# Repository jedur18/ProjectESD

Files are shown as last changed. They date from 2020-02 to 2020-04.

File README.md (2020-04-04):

# ESD project
**Project:** Motion Sensor Alarm (Group 2)
General Description: This project is divided in two groups. Group 1 will work with the motion sensor and will transmit a signal to the cloud when alarm is activated. Group 2 will work with the buzzer, display and keyboard in order to introduce the code to switch the alarm off.

**Group 2 description:** Our system will recive the signal of the activated alarm from the cloud by the LORA module. The idea then is to activate the buzzer to emit the sound. While the alarm is ringing the user will be able to introduce a secret code using the keyboard to switch the alarm off. In the display it will be showed the status of the system (Alarm ON/OFF), the code introduced and if it is correct or not.

**Distribution of the work:**
- EDU:
  - Basic part:
    - Numeric Keyboard: With this part digital I/O will be faced. I will also need to remove the bouncing of the buttons, deal with PCINTs (Pin change interruptions).
  - Individual Goals to reach 4/5 mark:
    - Display: SPI communication. Showing the system state, the code introduced by the user and if the code is correct or not.
    - Software protection--> Encryption. Asymmetric encryption if its possible (need to investigate on it)

- ALI:
  - basic part:
    - Buzzer: sendig out sound by the PWM signals as the LEDs.
    - LEDs control. Green:normal mode. Red:alarm mode. (LED blinking-->PWM)
  - More advansed part for us electronic backgrounded students is software development:
    - We are going to make the keypad unit and the sensor unit works as front end which will communicate to the back end server.
    - We are even going to make it possible for the system to be able to support more than one sensor and make it possibble for the master to identify which unit is detecting motions.

## EQUIPMENT:
- Murata CMWX1ZZABZLoRa Module:
	Datasheet:https://wireless.murata.com/datasheet?/RFM/data/type_abz.pdf
  - STM32L0x2:
		Documentation (Full information about micro): https://www.ece.uvic.ca/~ece355/lab/supplement/stm32f0RefManual.pdf
		With rust: https://docs.rs/stm32f0x2/0.1.0/stm32f0x2/

- Oled Display: SSD1306. 
	Datasheet: https://buildmedia.readthedocs.org/media/pdf/ssd1306/latest/ssd1306.pdf
	Website to order: https://cdon.se/hem-tradgard/oled-display-0-96-tum-med-128x64-vita-pixlar-i2c-ssd1306-p50542494
	Prize: 59kr
- Driver for Oled Display SSD1306
	Datasheet: https://cdn-shop.adafruit.com/datasheets/SSD1306.pdf
- LEDs: (Maybe available at lab)
	Red LED: https://se.rs-online.com/web/p/leds/2285988/
	Green LED: https://se.rs-online.com/web/p/leds/2286004/
- Numeric Keyboard:
	Website to order: https://www.elfa.se/en/3x4-matrix-keypad-adafruit-3845/p/30139179?queryFromSuggest=true
	Prize: 61.90kr
	Documentation: https://www.adafruit.com/product/1824
					https://www.futurlec.com/Keypad3x4.shtml
					Arduino libraries and documentation: https://playground.arduino.cc/Code/Keypad/
- Capacitors:
	6x100nF for decoupling: 
			for power supply:

- Resistors: 
	2x10k for pull Up and pull Down resistors for NRST and BOOT0: https://www.elfa.se/en/thick-film-smd-resistor-0805-10kohm-125mw-rnd-components-rnd-1550805s8f1002t5e/p/30056718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
	Prize: 0.4972 (ordering 4)
	for power supply: 
	
- Serial Wire Debug (SWD) to program and debug the MCU: 
	Website to oder: https://www.elfa.se/en/ampmodu-mod-ii-straight-male-pcb-header-through-hole-54mm-te-connectivity-826629/p/14371639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
	Prize: 5.78SEK
	Datasheet:https://www.elfa.se/Web/Downloads/_t/ds/8266xx_x_eng_tds.pdf?pid=14371639

- Power Supply:

- Buzzer: 
  - piezo buzzer (KMTG1603-1) : https://se.rs-online.com/web/p/piezo-buzzer-components/7675349/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
    - Datasheet: https://docs.rs-online.com/aa51/0900766b81113b92.pdf
  - Transistor: (MMBT2222A)
    - Datasheet: https://www.elfa.se/Web/Downloads/_p/df/Diotec-MMBT2222A_eng_ger_tds.pdf?pid=30146837

 - num-pad:
   - Rectifier Diodes: https://www.elfa.se/en/rectifier-diode-1206-taiwan-semiconductor-ts4148-rxg/p/30139387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
     - Datasheet: https://www.elfa.se/Web/Downloads/_t/ds/TS4148_RXG_eng_tds.pdf?pid=30139387
   - Buttons:
     - RND210-00204: https://www.elfa.se/en/pcb-tactile-switch-210-1no-57n-6mm-rnd-components-rnd-210-00204/p/30090660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
     - Datasheet: https://www.elfa.se/Web/Downloads/_t/ds/RND%20210-00204_eng_tds.pdf?pid=30090660
   
 - Antenn con: https://www.elfa.se/en/micro-coaxial-straight-socket-micro-coaxial-connector-50ohm-6ghz-molex-73412-0110/p/30076410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
   - datasheet: https://www.elfa.se/Web/Downloads/_t/ds/73412-0110_eng_tds.pdf?pid=30076410
   
 - Micro-USB B connector: https://www.elfa.se/en/socket-micro-usb-smd-wuerth-elektronik-629105150521/p/30009163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
   - Datasheet: https://www.elfa.se/Web/Downloads/40/32/629105150521.pdf?pid=30009163
   
 - Voltage Regulator:
   - LM1117ADJ: https://www.elfa.se/en/ldo-voltage-regulator-800ma-sot-223-texas-instruments-lm1117impx-adj-nopb/p/30019194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
   
 - LEDs:
   - Red:https://www.elfa.se/en/smd-led-640nm-1206-600mcd-30ma-kingbright-kptd-3216surc/p/17531032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
     - Datasheet: https://www.elfa.se/Web/Downloads/6_/en/csKingbright_SMD-LED-rot-KTPD3216_EN.pdf?pid=17531032
   - Green: https://www.elfa.se/en/smd-led-468nm-1206-700mcd-20ma-kingbright-kptd-3216qbc/p/17510753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
     - Datasheet: https://www.elfa.se/Web/Downloads/_t/ds/kptd-3216qbc-d_eng_tds.pdf?pid=17510753

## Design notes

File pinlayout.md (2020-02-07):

#PIN LAYOUT
# 1 -->
# 2 -->
# 3(GND) --> 
# 4 -->
# 5 -->
# 6 -->
# 7 -->
# 8 -->
# 9 -->
# 10 -->
# 11 -->
# 12 -->
# 13 -->
# 14(PB15/SPI2_MOSI) --> SPI 1306 oled display (D1)
# 15(PB14/SPI2_MISO) --> 
# 16(PB13/SPI2_SCK) --> SPI 1306 oled display (D0)
# 17(PB12/SPI2_NSS) --> SPI 1306 oled display (CS) :chip select
# 18 -->
# 19 -->
# 20 -->
# 21 -->
# 22 -->
# 23 -->
# 24 -->
# 25 -->
# 26 -->
# 27 -->
# 28 -->
# 29 -->
# 30 -->
# 31 -->
# 32 -->
# 33 -->
# 34(MCU_RST) --> SW_push//C(100NF)
# 35(PB8/I2C1_SCL) --> 
# 36(PB9/I2C1_SDA) --> SPI 1306 oled display (RES)
# 37(PB2/LPTIM1_OUT) --> ## Buzzer PWM OUTPUT (CHECK IF ITS CORRECT PIN for PWM)
# 38(PB7/LPTIM_IN2) -->
# 39(PB6/LPTM1_ETR) -->
# 40(PB5/LPTIM1_IN1) -->
# 41 -->
# 42 -->
# 43(BOOT0) --> 10K resistor
# 44 -->
# 45 -->
# 46 -->
# 47 -->

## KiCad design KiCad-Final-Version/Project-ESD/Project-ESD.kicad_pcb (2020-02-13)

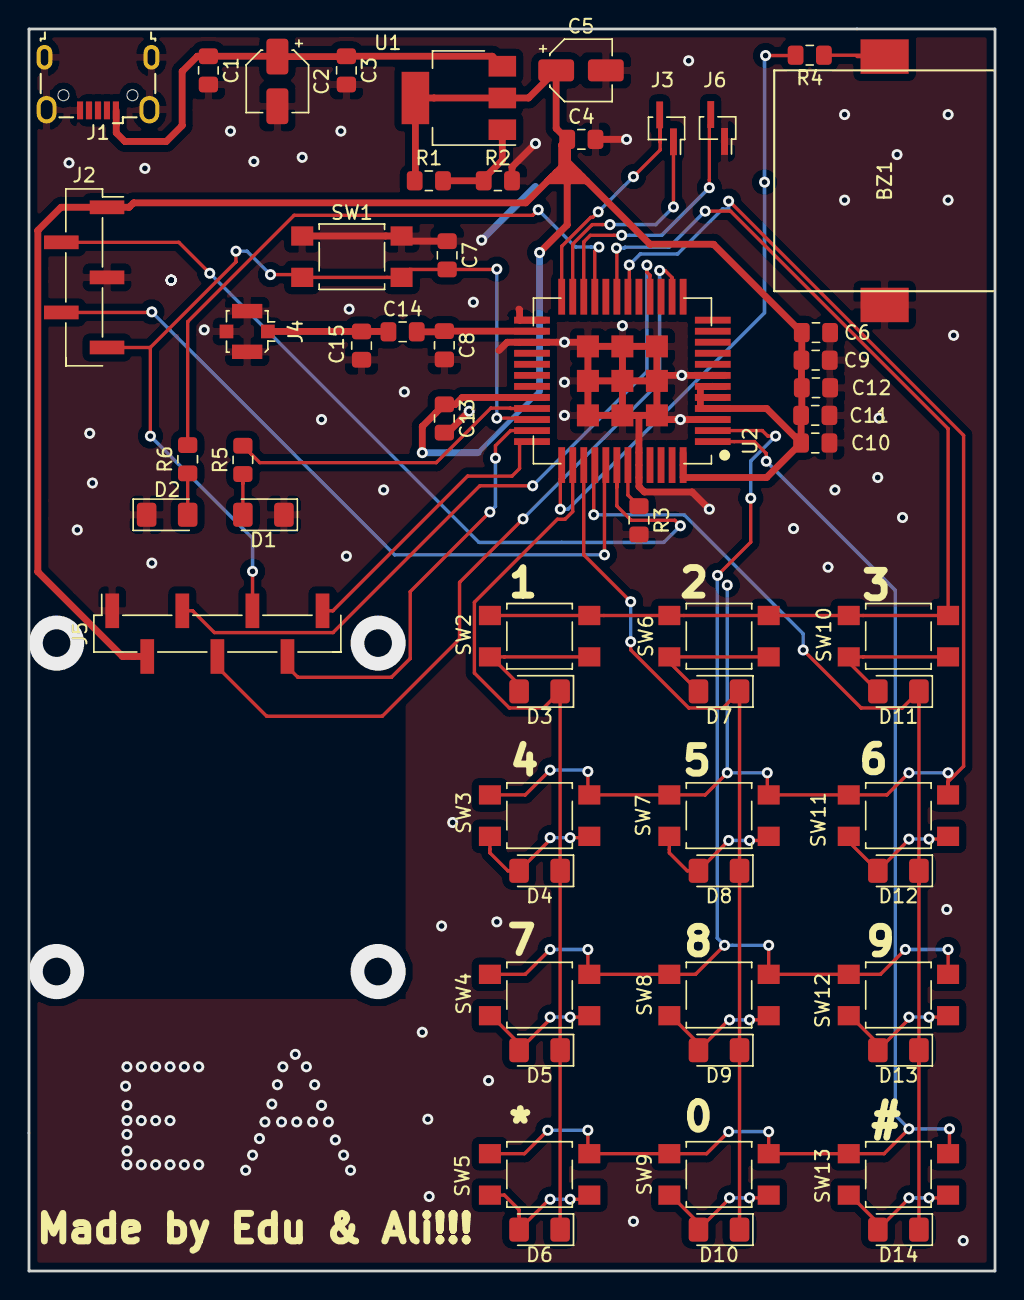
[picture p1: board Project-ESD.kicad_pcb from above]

Board: 2 copper layers, 70.0 x 90.0 mm, 57 parts (0 on the bottom side), 42 nets.

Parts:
BZ1: Buzzer; kmtg1603-1
C1, C3, C4, C7, C8, C15: 100n; C_0805_2012Metric_Pad1.15x1.40mm_HandSolder
C2, C5: 10u; CP_Elec_4x5.4
C6, C10: 10uF; C_0805_2012Metric_Pad1.15x1.40mm_HandSolder
C9, C13: 1uF; C_0805_2012Metric_Pad1.15x1.40mm_HandSolder
C11, C12: 0.1uF; C_0805_2012Metric_Pad1.15x1.40mm_HandSolder
C14: 100p; C_0805_2012Metric_Pad1.15x1.40mm_HandSolder
D1, D2: LED; LED_1206_3216Metric_Pad1.42x1.75mm_HandSolder
D3, D4, D5, D6, D7, D8, D9, D10, D11, D12, D13, D14: D; D_1206_3216Metric_Pad1.42x1.75mm_HandSolder
J1: USB_OTG; USB_Micro-B_Wuerth_629105150521
J2: Conn_01x05_Male; PinHeader_1x05_P2.54mm_Vertical_SMD_Pin1Right
J3, J6: Conn_01x02_Female; PinSocket_1x02_P1.00mm_Vertical_SMD_Pin1Right
J4: Conn_Coaxial; U.FL_Molex_MCRF_73412-0110_Vertical
J5: Conn_01x07_Male; PinHeader_1x07_P2.54mm_Vertical_SMD_Pin1Right
R1: 3.3k; R_0805_2012Metric_Pad1.15x1.40mm_HandSolder
R2: 5.6k; R_0805_2012Metric_Pad1.15x1.40mm_HandSolder
R3: 10k; R_0805_2012Metric_Pad1.15x1.40mm_HandSolder
R4: 680; R_0805_2012Metric_Pad1.15x1.40mm_HandSolder
R5, R6: 330; R_0805_2012Metric_Pad1.15x1.40mm_HandSolder
SW1, SW2, SW3, SW4, SW5, SW6, SW7, SW8, SW9, SW10, SW11, SW12, SW13: SW_Push; SW_SPST_TL3305C
U1: LM1117ADJ; SOT-223
U2: CMWX1ZZABZ-078; CMWX1ZZABZ_longer_pads

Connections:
+3V3: C4.1, C5.1, C6.1, C9.1, C10.1, C11.1, C12.1, C13.1, J2.1, J5.2, R1.1, U1.2, U1.4, U2.4, U2.5, U2.6, U2.32, U2.48
+5V: C1.1, C2.1, C3.1, J1.1, U1.3
BZ: R4.2, U2.37
COL1: D3.1, D4.1, D5.1, D6.1, U2.38
COL2: D7.1, D8.1, D9.1, D10.1, U2.39
COL3: D11.1, D12.1, D13.1, D14.1, U2.40
CS: J5.7, U2.36
D0: J5.3, U2.16
D1: J5.4, U2.14
DC: J5.6, U2.35
GND: BZ1.2, C1.2, C2.2, C3.2, C4.2, C5.2, C6.2, C7.1, C8.2, C9.2, C10.2, C11.2, C12.2, C13.2, C15.2, D1.1, D2.1, J1.5, J1.6, J2.3, J4.2, J5.1, J6.1, R2.2, R3.2, SW1.1, U2.3, U2.7, U2.25, U2.27, U2.44, U2.49, U2.50, U2.51, U2.52, U2.53, U2.54, U2.55, U2.56, U2.57
LED1: R5.2, U2.33
LED2: R6.2, U2.21
unnamed: BZ1.1, R4.1
unnamed: C14.1, C15.1, J4.1
unnamed: C8.1, C14.2, U2.26
unnamed: D1.2, R5.1
unnamed: D2.2, R6.1
unnamed: D3.2, SW2.2
unnamed: D4.2, SW3.2
unnamed: D5.2, SW4.2
unnamed: D6.2, SW5.2
unnamed: D7.2, SW6.2
unnamed: D8.2, SW7.2
unnamed: D9.2, SW8.2
unnamed: D10.2, SW9.2
unnamed: D11.2, SW10.2
unnamed: D12.2, SW11.2
unnamed: D13.2, SW12.2
unnamed: D14.2, SW13.2
unnamed: J2.2, U2.42
unnamed: J2.4, U2.41
unnamed: J3.1, U2.23
unnamed: J3.2, U2.24
unnamed: J6.2, U2.22
unnamed: R1.2, R2.1, U1.1
unnamed: R3.1, U2.43
RES: C7.2, J2.5, J5.5, SW1.2, U2.34
ROW1: SW2.1, SW6.1, SW10.1, U2.19
ROW2: SW3.1, SW7.1, SW11.1, U2.18
ROW3: SW4.1, SW8.1, SW12.1, U2.2
ROW4: SW5.1, SW9.1, SW13.1, U2.1

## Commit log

2020-02-07 Update
    Pinlayout
    Kicad first version
    [ESDproject.kicad_pcb, ESDproject.sch]
2020-02-10 Schemaitc update
    Add: SWD connector, SPI connections, antenna
    [ESDproject.sch]
2020-02-11 Update of schematic
    [ESDproject.sch]
2020-02-11 Schematic update
    [ESDproject.sch]
2020-02-12 Final Update Of PCB
    The grb files will come soon...
    [Project-ESD.kicad_pcb, Project-ESD.sch]
2020-02-13 Final verson 2
    [Project-ESD.kicad_pcb, Project-ESD.sch]
2020-02-13 Final verson with the gerber files(Final Verson 3)
    [Project-ESD-B.Cu.gbr, Project-ESD-B.Mask.gbr, Project-ESD-Edge.Cuts.gbr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]
2020-02-13 Final with correct Gerber files, (final Verson 4)
    [Project-ESD-B.Cu.gbr, Project-ESD-B.Mask.gbr, Project-ESD-Edge.Cuts.gbr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]
2020-03-19 Commit of the initial folder for the project. It contains working files for controlling LEDs and for controlling the buttons(wihtout interruptions). It also have the first version of PWM using LPTIME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
2020-04-03 This commit with add all the software part working. On the one hand it contain the four code files which contain pwm,adc,serial and gpio functionalitis (the minimun requirements for the project). For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
    [ESDproject.kicad_pcb, ESDproject.sch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]
